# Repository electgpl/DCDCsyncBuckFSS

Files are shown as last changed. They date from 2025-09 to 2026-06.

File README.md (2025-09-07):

# High-Performance Synchronous Buck Converter Module (AP64501)

This project is the design of a **DC-DC buck regulator module** based on the **AP64501**.  
It is mechanically and electrically compatible with the popular **LM2596-based low-cost Chinese modules**, using the same form factor, size, and pinout.  
However, this design provides **significant improvements** in terms of efficiency, thermal performance, EMI, and reliability.

---
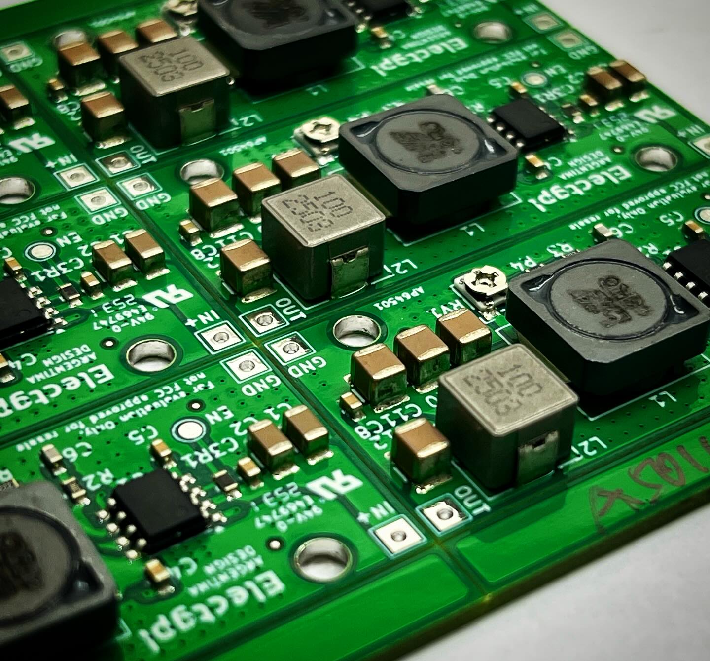
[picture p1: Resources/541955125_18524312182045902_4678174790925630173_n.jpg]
Module Preview

---

## 🔑 Key Features

- **Synchronous buck regulator (AP64501)**
  - Higher efficiency compared to asynchronous regulators.
  - Reduced heat generation under load.
- **Fixed Spread Spectrum (FSS)**
  - Lower EMI and more predictable spectral content.
- **Soft-Start (SS)**
  - Controlled inrush current during power-up.
- **Protections included**
  - Overcurrent protection (OCP).
  - Overvoltage protection (OVP).
  - Thermal shutdown (TSD).
- **Output filtering**
  - Additional **LC filter stage** for significantly reduced ripple.
- **PCB design**
  - **4-layer PCB** for improved heat spreading and ground integrity.
  - Optimized layout for EMI and thermal performance.
- **Thermal analysis**
  - Finite Element Analysis (FEA) performed.
  - Effective thermal resistance: **55 °C/W** (with 1 oz copper).

---

## 📐 Form Factor

- Pinout, size, and footprint are **drop-in compatible** with standard LM2596-based modules.  
- This allows easy replacement in existing designs, providing an **immediate upgrade** without redesigning the host PCB.

---

## 📊 Performance Advantages over LM2596 Modules

- ✅ Higher efficiency → less power loss.  
- ✅ Lower EMI thanks to fixed-frequency operation and optimized layout.  
- ✅ Lower output ripple due to additional LC stage.  
- ✅ Improved thermal performance with 4-layer PCB and synchronous design.  
- ✅ Built-in protections increase reliability and robustness.

---

## 🛠 Applications

- Embedded systems.  
- IoT devices.  
- RF front-ends (low-ripple supply requirement).  
- General-purpose regulated DC power supply.  
- Replacement for LM2596 modules in existing projects.

---

## 📄 Documentation

- [AP64501 Datasheet (Diodes Incorporated)](https://www.diodes.com/assets/Datasheets/AP64501.pdf)  
- Thermal FEA analysis results included in `/docs`.  
- PCB design files in `/hardware`.

---

## 🚀 Status

- ✅ Schematic design complete.  
- ✅ PCB layout (4-layer) completed.  
- ✅ Thermal simulation results validated.  
- 🔜 Hardware prototyping and testing in progress.

---

## 📷 Preview

*(Add photos, renderings, or thermal plots here when available.)*

---

## 📜 License

This project is released under the **MIT License**.  
See the [LICENSE](LICENSE) file for details.

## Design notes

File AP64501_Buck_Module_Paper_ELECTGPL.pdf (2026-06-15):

# 5 A Spread-Spectrum Synchronous Buck Module with a Two-Stage Output Filter: Design and Experimental Characterization

Sebastián Caccavallo
Electgpl
Advanced Hardware Design | Aerospace - Military - Medical

Abstract—This paper presents the design and experimental characterization of a 5 A step-down (buck) power module intended as a higher-performance, pin- and form-compatible replacement for the ubiquitous LM2596 module. The converter is built around the Diodes AP64501 synchronous buck (3.8–40 V input, peak-current-mode control at 570 kHz, integrated 45 mΩ/20 mΩ power MOSFETs and ±6 % frequency spread spectrum) and is implemented on a four-layer printed circuit board with a continuous return-reference plane and a thermal via array beneath the exposed pad. A distinctive feature is a two-stage output filter in which the control-loop feedback is deliberately sampled before the second-stage LC network, preserving the manufacturer reference type-II compensation while relegating the post-filter to a passive role. The module was characterized at Vin≈12 V, Vout≈4.8 V, up to 1.155 A. Measured peak efficiency is 87.8 %, output ripple is 7.8 mV
pp

(≈0.16 % of Vout), the hotspot temperature is 34.8 °C (ΔT≈11 °C), and radiated emissions remain below the displayed CISPR 32 envelope with ≈3 dB worst-case margin near 200 MHz. The 2.23 % load regulation is shown—analytically and by inspection of the schematic—to originate almost entirely from the DC resistance of the out-of-loop second-stage inductor rather than from the regulation loop. Design trade-offs and recommended follow-up measurements are discussed.

Index Terms—Synchronous buck converter, AP64501, spread-spectrum modulation, electromagnetic interference (EMI), output-voltage ripple, two-stage LC filter, load regulation, output impedance, power-distribution network, CISPR 32, four-layer PCB.

Manuscript compiled June 14, 2026 (Rev. C). The author is with Electgpl, Buenos Aires, Argentina (https://github.com/electgpl). Design performed in KiCad 9.0.4; device under test based on the Diodes AP64501SP-13. Prototype labeled “For evaluation only — not FCC approved for resale.” Ambient temperature for the thermal measurement was not logged and is assumed ≈24 °C where noted.

I. Introduction

The LM2596-based step-down module is one of the most widely deployed power bricks in hobbyist and low-volume industrial designs, owing to its low cost and convenient form factor. Its limitations are equally well known: an asynchronous topology with a Schottky catch diode, a switching frequency near 150 kHz, modest light-load efficiency, comparatively high output ripple, and no provision for electromagnetic-interference (EMI) mitigation. This work targets a mechanically compatible replacement that retains the familiar IN+/GND/OUT/EN interface while substantially improving switching performance, output ripple, thermal behavior and radiated emissions.
The design is built around the Diodes AP64501, a 5 A synchronous buck converter with a 3.8–40 V input range, peak-current-mode control at a fixed 570 kHz internal clock, fully integrated 45 mΩ (high-side) and 20 mΩ (low-side) power MOSFETs, a proprietary gate-driver scheme that controls switch-node ringing, and frequency spread spectrum (FSS) with ±6 % jitter for EMI reduction [1]. The contribution of this paper is twofold: (i) a complete, reproducible design record (schematic, bill of materials and four-layer stack-up) of an EMI-aware module, and (ii) a full experimental characterization—efficiency, output ripple, thermal imaging and radiated emissions—together with an analysis of the two-stage output-filter trade-off that explains the measured efficiency and load-regulation figures.

Electgpl — Technical Report | AP64501 Buck Module · Design and Characterization

II. Power-Stage Architecture and Schematic

A. Integrated Converter
The AP64501 employs fixed-frequency peak-current-mode control with an internal 0.8 V ±1 % reference, programmable soft-start, cycle-by-cycle current limit with entry into hiccup mode after 512 consecutive limit events, output over-voltage protection, EN-programmable under-voltage lockout and thermal shutdown [1]. The device is supplied in an SO-8EP package whose exposed pad provides the primary thermal path.
B. Two-Stage Power Train and Capacitance Partition
The converter migrates the LM2596 interface from a 150 kHz asynchronous stage to a 570 kHz synchronous one and adds a second-stage output filter. It is essential to distinguish which output capacitance is inside and outside the control loop, since this governs both stability and load regulation. Table I summarizes the partition.

TABLE I
Output Capacitance Partition and Loop Relationship
Block | Components | Relationship to control loop
Input | C1, C2 = 2×10 µF + C3 100 nF | Input decoupling / input switching loop
First stage (buck) | L1 3.6 µH + C8 100 nF + C9/C10/C11 =
| 66 µF | Regulated node — feedback is sensed here

Second stage

(post-filter) | L2 10 µH + C12 22 µF | Outside the loop — passive ripple/EMI attenuation

The first-stage node presents 66 µF of ceramic capacitance—identical to the 3×22 µF Cout of the manufacturer reference design [1]—so the reference type-II compensation (R2 = 15.8 kΩ, C6 = 2.7 nF) remains valid. The post-filter (L2, C12) is added downstream of the feedback tap and therefore does not alter the loop, at the cost of the DC drop of L2 (Section V-C).

C. Feedback Sensed Before the Filter
A design note on the schematic states explicitly that the feedback sample is taken before the LC filter, so as not to alter the compensation phase of the converter nor add a new pole. This is a deliberate and well-founded choice: it keeps the loop identical to the reference (stable, with 66 µF and type-II compensation) and leaves the second stage as a purely passive filter. The output is made adjustable by the divider
Vout = Vref · ( 1 + Rtop / Rbot ) | (1)

with upper branch R4 (100 Ω) in series with trimmer RV1 (47 kΩ) taken from the regulated node, lower resistor R3 (2.2 kΩ) to ground, and a feed-forward capacitor C7 (10 nF) across the upper branch to introduce a phase-lead zero. With Vref=0.8 V and R3=2.2 kΩ, the measured 4.86 V set-point corresponds to Rtop≈11 kΩ (RV1 at roughly one quarter of travel); the theoretical adjustment range is ≈0.84 V to ≈18 V, bounded in practice by Vin headroom.

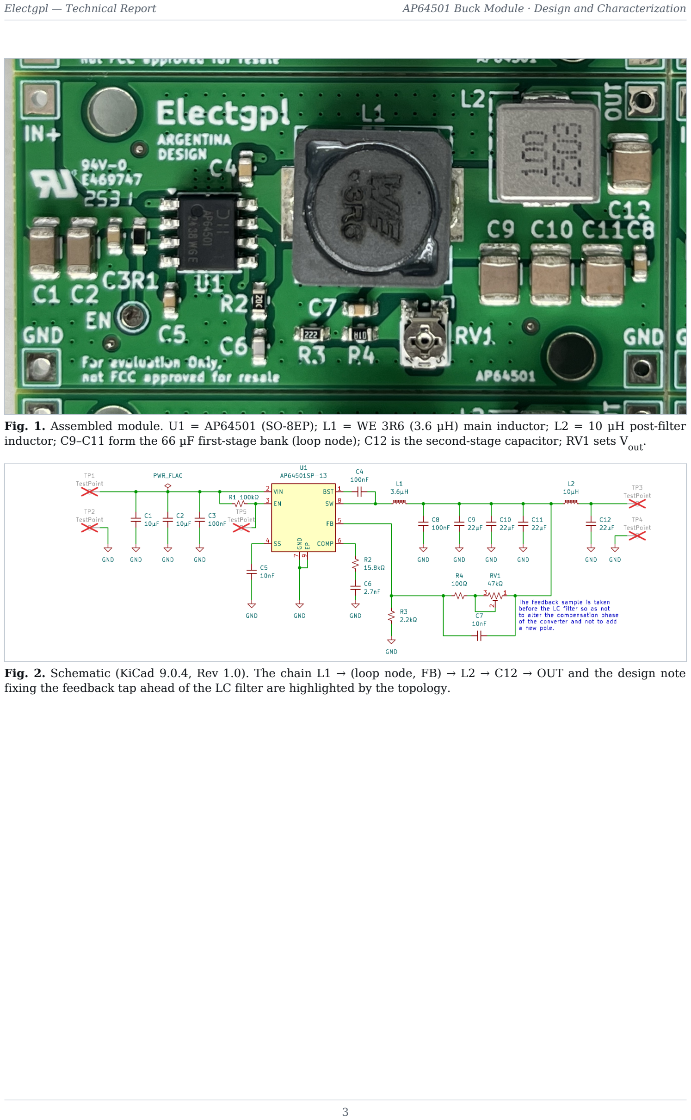
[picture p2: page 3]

Fig. 1. Assembled module. U1 = AP64501 (SO-8EP); L1 = WE 3R6 (3.6 µH) main inductor; L2 = 10 µH post-filter inductor; C9–C11 form the 66 µF first-stage bank (loop node); C12 is the second-stage capacitor; RV1 sets Vout.

Fig. 2. Schematic (KiCad 9.0.4, Rev 1.0). The chain L1 → (loop node, FB) → L2 → C12 → OUT and the design note fixing the feedback tap ahead of the LC filter are highlighted by the topology.

TABLE II
Bill of Materials
Ref. | Value | Function
U1 | AP64501SP-13 | 5 A synchronous buck (SO-8EP, EP to GND)
L1 | 3.6 µH (WE 3R6) | Main inductor — first stage
L2 | 10 µH | Post-filter inductor — second stage
C1, C2 | 10 µF each | Input capacitors (ceramic)
C3 | 100 nF | Input high-frequency decoupling
C4 | 100 nF | Bootstrap (BST–SW)
C5 | 10 nF | Soft-start (SS)
C6 | 2.7 nF | Type-II compensation (COMP)
C7 | 10 nF | Feedback feed-forward
C8 | 100 nF | First-stage output, high frequency
C9, C10, C11 | 22 µF each (66 µF) | First-stage bulk (loop node)
C12 | 22 µF | Second-stage output (post-filter, out of loop)
R1 | 100 kΩ | EN pull-up / UVLO setting
R2 | 15.8 kΩ | Type-II compensation (COMP)
R3 | 2.2 kΩ | Feedback divider (lower)
R4 | 100 Ω | Feedback divider (upper series)
RV1 | 47 kΩ (trimmer) | Output-voltage adjustment
TP1–TP5 | — | Test points (Vin, EN, Vout, nodes)
FID1–FID3 | — | Assembly fiducials

III. Printed-Circuit Implementation

The board is realized on four copper layers, a decision central to the measured power-integrity and EMI performance. Table III lists the function of each layer as inferred from the copper artwork (Fig. 3).

TABLE III
Function of Each Copper Layer
Layer | Design observation | Implication
TOP | Components and power copper: Vin input, a compact
SW node, the first-stage (loop) node and OUT.

Input switching loop and SW node of minimal area → reduced di/dt radiating area.

INNER1 Continuous reference (GND) plane directly beneath TOP.

Low-inductance image-current return for every power trace → key to the clean CISPR scan.

INNER2 | Additional plane (GND/power) with stitching-via field. | Reinforces the PDN and inter-layer
shielding; low plane impedance.

BOTTOM Sensitive signal routing (feedback) plus GND fill.

Feedback routed away from SW, referenced to an inner plane → low noise on the regulated node.

Two cross-cutting features stand out: a dense GND stitching-via field that ties the planes together across all layers, providing return continuity and shielding; and a thermal via array beneath the exposed pad of U1 (white outline in Fig. 3), which channels heat from the EP into the inner and bottom copper—consistent with the ≈12 °C/W effective thermal resistance estimated in Section V-E. The continuous return plane on INNER1 under the TOP power copper, the compact SW node and the device FSS jointly account for the low radiated-emission levels

(Section V-F).

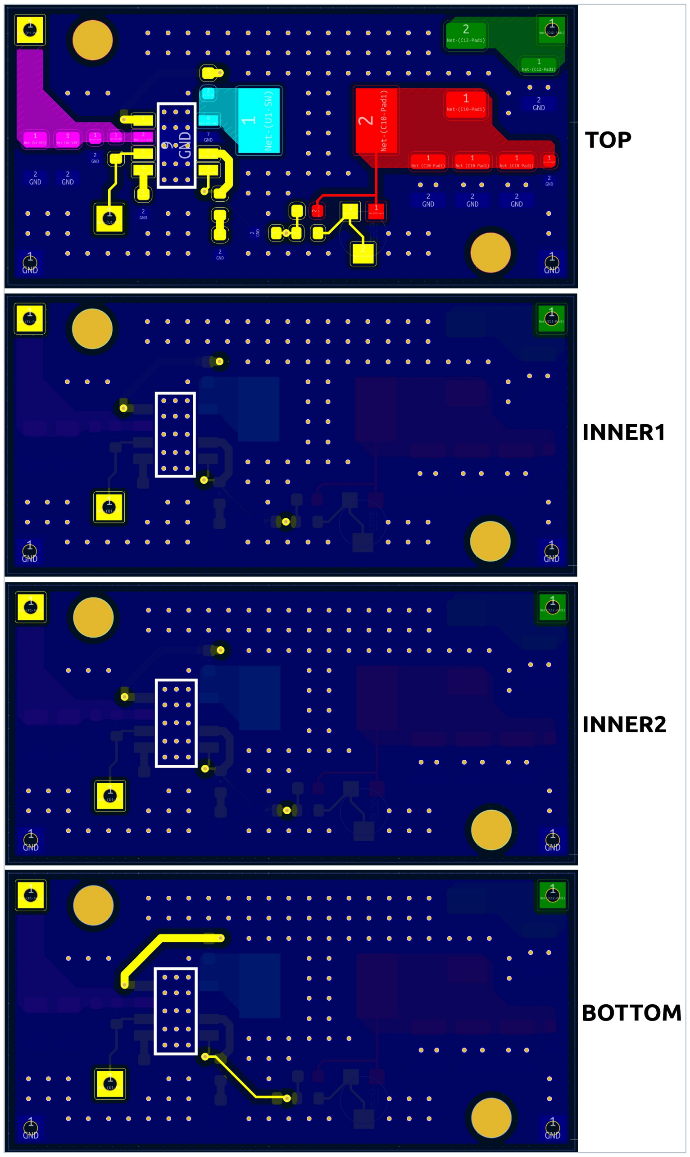
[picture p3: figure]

Fig. 3. Four-layer artwork (TOP / INNER1 / INNER2 / BOTTOM). White outline: thermal/GND via array beneath the U1 exposed pad. Yellow dots: the GND stitching-via field.

IV. Experimental Method

The module was supplied from a bench source at Vin≈12 V (logged average 11.879 V) with the output trimmed to ≈4.8 V. An electronic load swept the output current from 0 to 1.155 A in 30 steps, averaging 16 readings per point with a 0.25 s settling interval. Table IV lists the instrumentation and conditions.

TABLE IV
Test Conditions and Instrumentation
Quantity / instrument | Configuration
Input voltage | Vin≈12 V (measured 11.879 V), bench supply
Output voltage | ≈4.8–4.86 V, set by RV1
Load sweep | Electronic load, 30 steps, 0→1.155 A, 0.25 s settle, 16-sample average
Bench power budget | Pbudget=15 W (caps the swept Iout)
Ripple | Rigol oscilloscope, CH1 5 mV/div, statistical Ripple function (1000 counts),
| 20 MHz bandwidth limit
Thermal | IR camera (iron palette), board in still air, no heatsink or forced flow
EMC | Radiated emissions 30 MHz–1 GHz against a CISPR 32 envelope
| (40/47 dBµV/m)

The sweep terminated at 1.155 A because of the 15 W bench budget, not a device limitation: the automated report records “3 %/5 %/10 % drop: not reached” and “no cutoff,” meaning the output never sagged enough to trigger the drop thresholds and the AP64501 current limit was not reached. The present campaign therefore covers operation up to ≈1.16 A; determining the true maximum output current (toward the 5 A device rating) requires a higher-power bench and is left as future work (Section VI).

V. Results and Discussion

Table V collects the headline measured figures; the subsections that follow analyze each result.

| TABLE V
Summary of Measured Performance
Parameter | Result | Condition / note
Vout, no load | 4.861 V | I out=0 (trimmed by RV1)
Vout, full load | 4.752 V | I out=1.155 A
Load regulation | 2.23 % (Rout,eq≈94 mΩ) | 0→1.155 A; root cause in V-C
Max. swept Iout | 1.155 A | bench-limited; Ilim not reached
Peak / full-load efficiency | 87.8 % @0.84 A / 87.0 % @1.16 A | max. loss 0.90 W

Output ripple (pp, BW
20 MHz) | 7.76 mV typ. / 11.84 mV max | ≈0.16 % of Vout
Thermal hotspot | 34.8 °C | ΔT≈11 °C over assumed ~24 °C ambient
Radiated emissions | Below 40/47 dBµV/m envelope | ≈3 dB worst-case margin (~200 MHz)
A. Efficiency and Power Balance

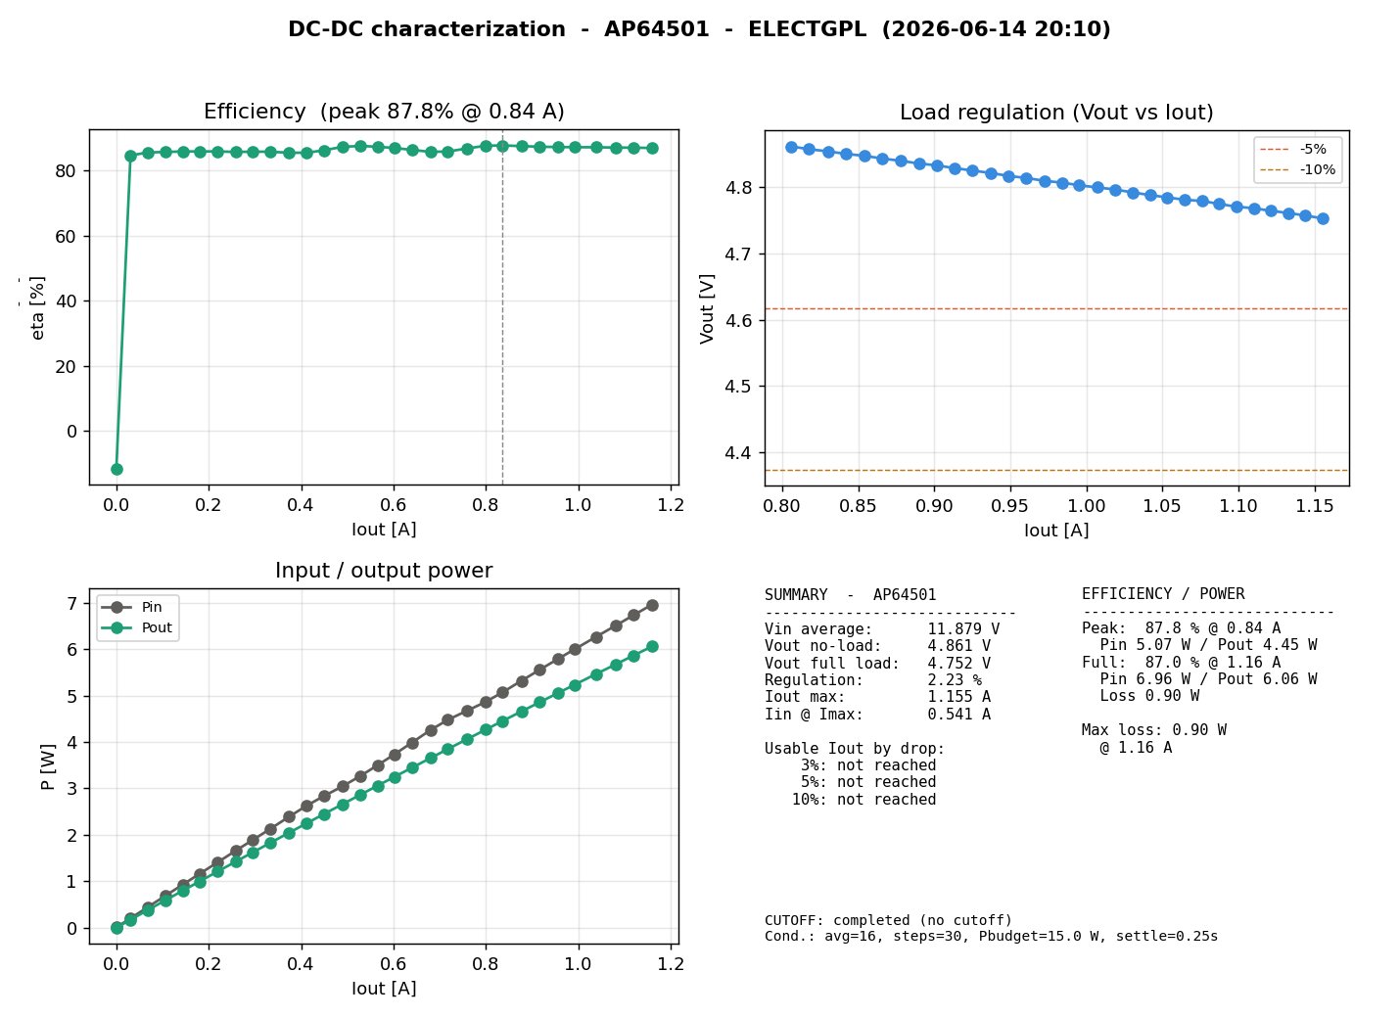
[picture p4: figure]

Fig. 4. Automated DC-DC characterization: efficiency η(Iout), load regulation Vout(Iout) and input/output power, with the bench numeric summary at right.

Efficiency is flat at 86–88 % across the continuous-conduction region, peaking at 87.8 % at 0.84 A and reaching 87.0 % at full load (1.16 A), where the total loss is 0.90 W. The first sweep point (Iout→0) falls below zero by definition of η=Pout/Pin at no load (Pout=0 while the device still draws switching and quiescent current); it is an artifact, not a physical efficiency.
For the 12 V→4.8 V operating point the bare-IC reference design exceeds 90 % [1],[2]; the module delivers ≈87–88 %, a 3–6-point module-level deficit. With the bill of materials now confirmed, the dominant contributors are, in order: (i) the DC resistance of the out-of-loop second-stage inductor L2 (10 µH), which carries the full DC output current—at DCR≈80 mΩ this is I²·DCR≈0.11 W at 1.16 A, about 12 % of the measured loss; (ii) the DCR of L1 and interconnect; and (iii) the operating point, since 1.16 A is well below the peak-efficiency load of a 5 A converter, so fixed losses weigh proportionally more. Conduction losses in the integrated
MOSFETs | are | bounded: | high-side | ≈D·I²·RHS=0.40·1.16²·0.045≈24 | mW | and | low-side
≈0.60·1.16²·0.020≈16 mW. The trade-off is consistent with the design intent: the post-filter trades a few points of efficiency for ripple and EMI.
B. Inductor Ripple, CCM and Filter Corners
The peak-to-peak ripple current of the main inductor in steady state is
| | ΔIL

= Vout(Vin − Vout) / (Vin L1

| | | | f sw
| | | | ) | | | (2)

which evaluates to ΔIL
≈1.40 A
| | | pp

(≈28 % of the 5 A rating; the usual 20–40 % guideline). The inductor-current valley at 1.16 A is 1.16−0.70=0.46 A>0, so the converter operates in continuous conduction (CCM); the CCM/PFM boundary lies at ≈0.70 A. Each LC corner follows from

| | | f c
= 1 / ( 2π √(L C) ) | (3)

yielding the values in Table VI.

TABLE VI
Distributed-Element and Filter Parameters
Stage / quantity | Expression | Value
First-stage LC (in loop) | f
| c1=1/(2π√(L1·66 µF)), L1=3.6 µH | ≈10.3 kHz
Second-stage LC (post-filter) | f
| c2=1/(2π√(L2·C12)), L2=10 µH, C12=22 µF | ≈10.7 kHz

Second-stage attenuation
@570 kHz | (f
| sw
| /fc2)² (ideal, before C12 ESR zero) | ≈69 dB

Second-stage characteristic
impedance | Z0
| =√(L2/C12) | ≈0.67 Ω

The ≈60–70 dB of passive attenuation provided by the second stage at the switching frequency is the quantitative explanation for the very low measured ripple (Section V-D). A damping caveat applies: with Z0

≈0.67 Ω and only the L2 DCR (~80 mΩ) as damping, the second-stage quality factor is high (≈8) and, being outside the loop, may appear as ringing near 10.7 kHz at the OUT terminal under load steps. This should be verified with a load-transient test (Section VI); if present, an RC snubber across C12 damps it without touching the loop.

C. Load Regulation and Output Impedance
The measured load regulation is 2.23 % (4.861→4.752 V from no load to 1.155 A): a 109 mV drop over 1.155 A, equivalent to a static output resistance
Rout,eq = ΔVout / ΔIout ≈ DCRL2 + Rint ≈ 94 mΩ | (4)

The schematic confirms the root cause: feedback is sensed at the first-stage node, by explicit design choice, so the loop regulates that node accurately while the DC resistance of L2 (10 µH) lies outside the loop and appears in full as load droop at OUT. The 94 mΩ figure is fully compatible with the DCR of a compact 10 µH molded inductor (≈60–90 mΩ) plus trace and connector resistance—not with a loop deficiency, whose intrinsic DC regulation is <0.5 %.
The decision is technically sound: sensing after L2 would bring the second stage inside the loop, adding an LC pole that erodes phase margin—precisely what the design avoids. Three options exist, in increasing order of intervention: (a) accept and specify the 94 mΩ as the module output impedance (simplest and most honest for a datasheet); (b) reduce the L2 DCR (a larger-section, lower-DCR inductor) to lower the droop without touching the loop; and (c), only if the application demands tight regulation at OUT, sense in Kelvin after L2 with a feed-forward/phase-lead network that restores the high-frequency information of the pre-L2 node and preserves margin, at the cost of added compensation complexity. A four-wire measurement of the L2 DCR is recommended first, to confirm it dominates the 94 mΩ.
D. Output Ripple and Noise

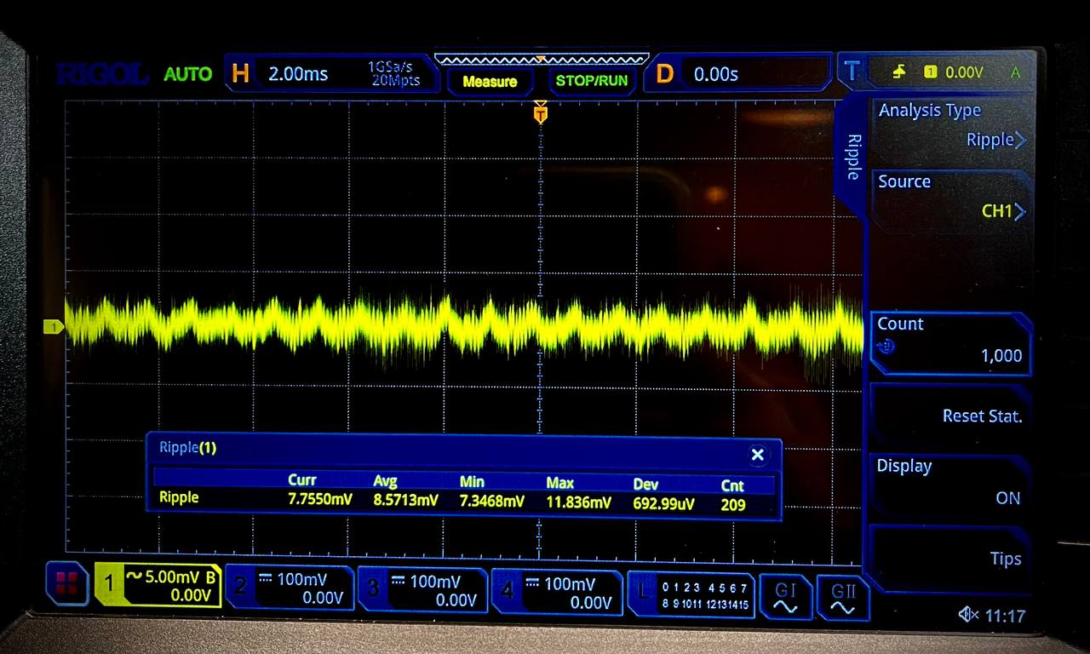
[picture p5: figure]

Fig. 5. Output ripple (Rigol, 5 mV/div, 20 MHz bandwidth limit, 1000 counts): Vpp

7.755 mV (mean
8.571, max 11.836, σ 0.69 mV).

Output ripple-plus-noise is 7.76 mV
pp

(mean 8.57, max 11.84), i.e. ≈0.16 % of Vout—a strong result and the direct benefit of the second-stage post-filter (Section V-B: ≈69 dB attenuation at f
sw

). The 20 MHz bandwidth limit (indicator “B”) was engaged, standard practice to bound RF pickup.
Two measurement caveats keep the figure defensible. First, the 2 ms/div timebase does not resolve the 570 kHz fundamental (1.75 µs period); the instrument’s Ripple function computes V
pp

statistically over the whole record (≈20 ms), so the value is valid as peak-to-peak ripple-plus-noise but mixes switching ripple with low-frequency wander and any pickup. Second, a zoomed capture (~500 ns/div) with a tip-and-barrel probe across C12—eliminating the alligator ground loop—should confirm the switching-ripple waveform; the ≈8 mV
pp

figure is expected to
hold or improve.
E. Thermal Performance

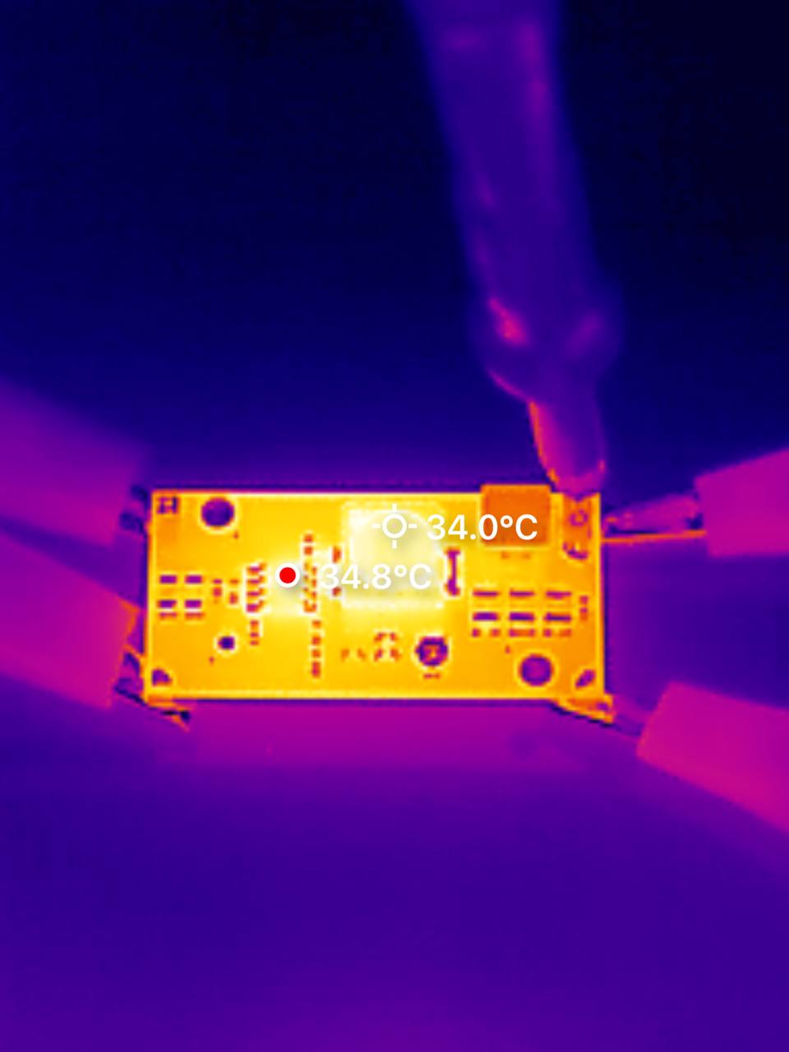
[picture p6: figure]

Fig. 6. Thermography. Crosshair 34.0 °C; spot 34.8 °C. Board in still air, no heatsink.

Operating in still air without heatsink or forced ventilation, the hotspot reads 34.8 °C and the board averages ≈34.0 °C. Assuming an ambient of ≈24 °C (not logged), the rise is ΔT≈11 °C for ≈0.9 W of loss, giving an effective hotspot-to-ambient thermal resistance of ≈12 °C/W—excellent for an SO-8EP with exposed pad on four layers with a thermal via array (Section III). An emissivity caveat applies: IR cameras under-read shiny metal surfaces (inductor can, IC body) owing to low emissivity, whereas readings on the PCB solder mask (ε≈0.9) are reliable; metallic parts may therefore be somewhat hotter than displayed. Even so, the margin is wide: the temperature confirms ample headroom to operate well above 1.16 A before any thermal limit.

F. Radiated Emissions (CISPR 32)

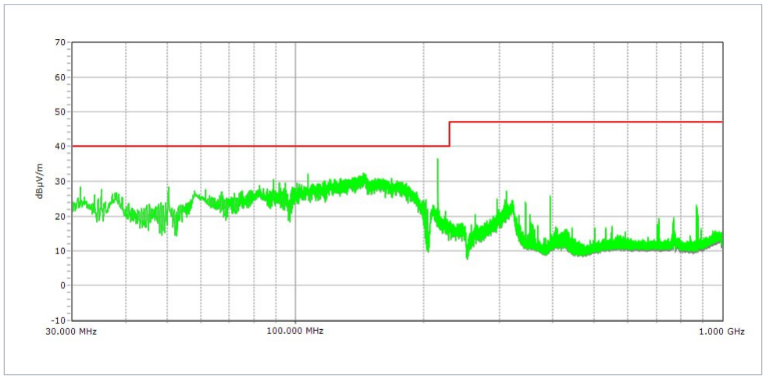
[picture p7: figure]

Fig. 7. Radiated emissions 30 MHz–1 GHz (green) against the limit envelope (red): 40 dBµV/m (30–230 MHz) and 47 dBµV/m (230 MHz–1 GHz).

The trace remains below the envelope across the band. The displayed limits (40/47 dBµV/m) correspond to CISPR 32 Class B at 3 m (equivalently Class A at 10 m) [4]. The measured level mostly lies between 20 and 35 dBµV/m, with a broadband hump between ≈100 and ≈200 MHz reaching ≈37 dBµV/m—the worst case, at ≈3 dB margin; above 230 MHz the margin exceeds 10 dB.
This is consistent with the design: the AP64501 FSS (±6 %) spreads each switching harmonic and lowers peak-detector levels [1]; the continuous return plane on INNER1 under the TOP power copper minimizes di/dt loop area; and the second-stage post-filter attenuates common-mode current toward the output cabling—the principal radiation mechanism in modules of this type. The 100–200 MHz hump has the signature of common-mode current on the I/O cables rather than a direct switching harmonic, and is the feature to watch for additional margin (an input/output ferrite bead or reinforced common-mode filtering). The scan is a pre-compliance peak-detector measurement; the distance, antenna and chamber are not recorded, and quasi-peak/average detectors are not shown. It is adequate to validate the design and estimate margin, but formal conformance requires an accredited measurement.

VI. Conclusion and Recommended Work

A four-layer, EMI-aware 5 A synchronous buck module was designed and characterized as a higher-performance, form-compatible alternative to the LM2596 module. At 12 V→4.8 V it achieves 570 kHz synchronous switching, ≈8 mV
pp

output ripple, a wide thermal margin (ΔT≈11 °C for ≈0.9 W), and radiated emissions below the displayed CISPR 32 envelope, with no protection event over the swept range. The two seemingly weak figures—≈87 % efficiency and 2.23 % load regulation—are shown to be the quantified, deliberate consequence of a two-stage output filter with pre-filter feedback, not a defect: the load droop is dominated by the out-of-loop L2 DC resistance, and the efficiency deficit is largely the same series resistance plus a light operating point for a 5 A device. Table VII lists the recommended follow-up measurements that would close the remaining open items.

TABLE VII
Recommended Follow-up Measurements
# | Action | Objective

1 | Four-wire DCR of L1 and L2; re-test toward Ilim/thermal rollback (3–5 A) on a higher-power bench. | Quantify the efficiency/regulation split; establish true maximum current (now bench-limited to 1.16 A).
2 | Load-transient (step) test observing OUT and the loop node. | Check for the ≈10.7 kHz second-stage ringing (Q≈8) outside the loop; decide on an RC snubber across C12.
3 | Zoomed ripple capture (~500 ns/div) with a tip-and-barrel probe across C12. | Quantify true switching ripple, separated from low-frequency content and pickup.
4 | If tight regulation is required: lower-DCR L2, or Kelvin sensing after L2 with feed-forward. | Reduce the 94 mΩ output impedance while preserving phase margin.
5 | Quasi-peak pre-compliance; mitigate common mode on I/O cabling (ferrite bead) over the 100–200 MHz hump. | Secure margin before an accredited measurement.
6 | Thermal sweep vs. load with logged ambient and, where applicable, at Vin=40 V. | Map Rθ/derating (a buck’s thermal worst case is usually at high Vin).

References

[1] Diodes Incorporated, “AP64501 — 3.8 V to 40 V Input, 5 A Low IQ
| | Synchronous Buck with Programmable
Soft-Start Time,” Datasheet DS41980, Rev. 5. Key parameters: 5 A, peak-current-mode, f
sw

=570 kHz, Rds(on)
45/20 mΩ, FSS ±6 %, Vref=0.8 V, reference Cout=3×22 µF, L=3.6 µH (5 V), SO-8EP.
[2] Diodes Incorporated, “AP64501SP-EVM — 40 V, 5 A, Low IQ
| | Synchronous DC-DC Buck Converter Evaluation
| Board User Guide.”
[3] Würth Elektronik, AP64501 reference-design data (3.6 µH “3R6” inductor), we-online.com, ICref / Diodes
| Incorporated section.

[4] CISPR 32:2015 / EN 55032, “Electromagnetic Compatibility of Multimedia Equipment — Emission Requirements,” radiated-emission Class A/B limits (40/47 dBµV/m, class- and distance-dependent).
[5] Good practice for switching-converter ripple measurement: tip-and-barrel / coaxial probing at the output capacitor with a 20 MHz bandwidth limit to bound RF pickup.

This document was compiled from the KiCad project (schematic Rev 1.0, four-layer artwork) and the bench reports of the device under test (automated DC-DC characterization, thermography, ripple and radiated emissions) dated 2026-06-14. Derived quantities (Rout,eq, ΔIL

, LC corners, attenuation, loss balance, effective Rθ) were computed from those data under the assumptions stated in each section. The DCR of L1/L2 and the true maximum output current remain to be measured directly.

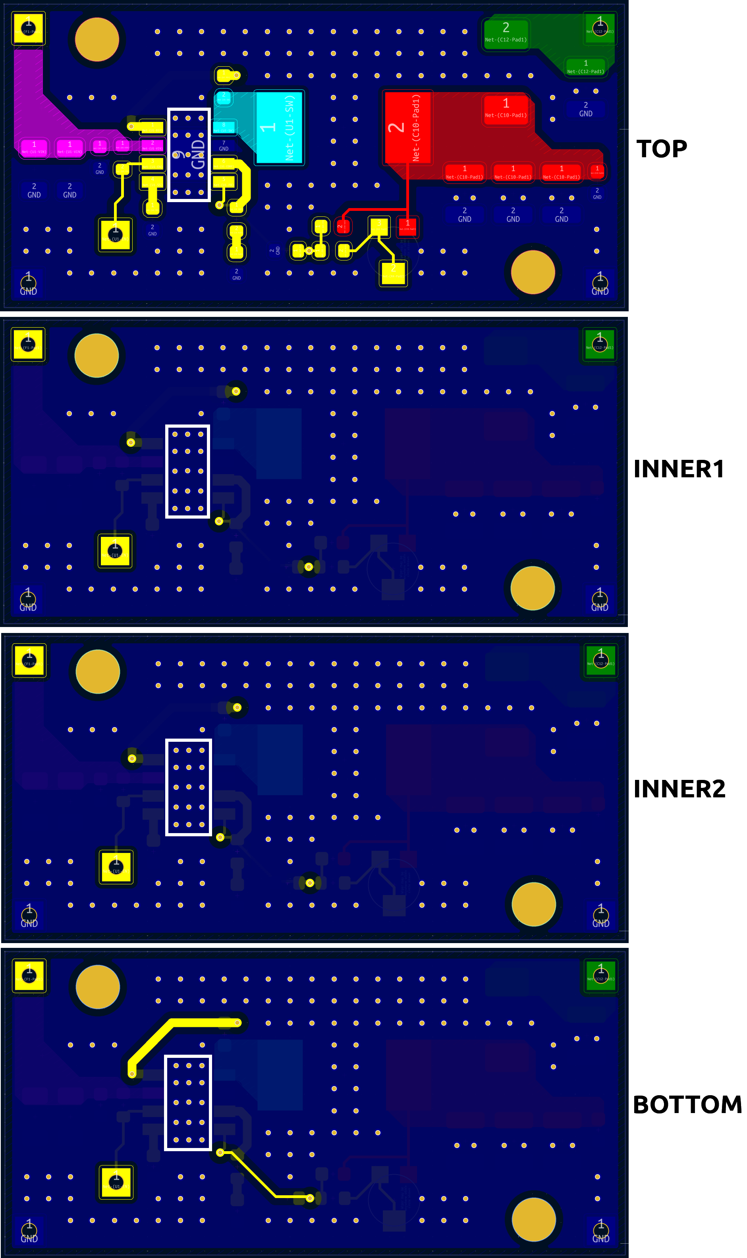
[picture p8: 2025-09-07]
PCB/EMI_SS_Supply_Electgpl/Multilayer.png

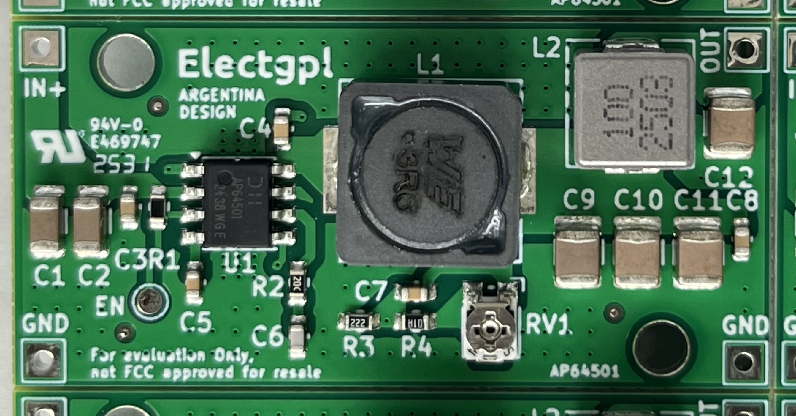
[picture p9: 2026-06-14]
Resources/Foto_PCBA.jpg

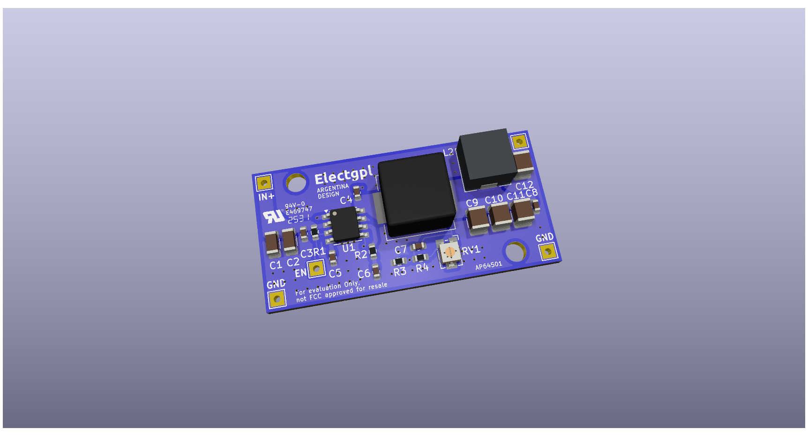
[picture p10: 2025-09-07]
PCB/EMI_SS_Supply_Electgpl/EMI_SS_Supply_Electgpl.png

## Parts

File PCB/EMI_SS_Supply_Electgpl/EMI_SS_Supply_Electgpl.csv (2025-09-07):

Reference | Qty | Value | MPN# | DNP | Footprint
C1,C2 | 2 | 10µF | CL31B106KBHNNNE |  | Capacitor_SMD:C_1206_3216Metric
C3,C4,C8 | 3 | 100nF | 885012206095 |  | Capacitor_SMD:C_0603_1608Metric
C5,C7 | 2 | 10nF | 885012206065 |  | Capacitor_SMD:C_0603_1608Metric
C6 | 1 | 2.7nF | GRM1885C1H272JA01D |  | Capacitor_SMD:C_0603_1608Metric
C9,C10,C11,C12 | 4 | 22µF | CL32B226KOJNNNE |  | Capacitor_SMD:C_1210_3225Metric
L1 | 1 | 3.6µH | 7447797360 |  | Inductor_SMD:L_Vishay_IHLP-4040
L2 | 1 | 10µH | SRP7050AA-100M |  | Inductor_SMD:L_Wuerth_HCM-7050
R1 | 1 | 100kΩ | CRCW0603100KFKEA |  | Resistor_SMD:R_0603_1608Metric
R2 | 1 | 15.8kΩ | CR0603-FX-1582ELF |  | Resistor_SMD:R_0603_1608Metric
R3 | 1 | 2.2kΩ | ERA-3AEB222V |  | Resistor_SMD:R_0603_1608Metric
R4 | 1 | 100Ω | AT0603DRD07100RL |  | Resistor_SMD:R_0603_1608Metric
RV1 | 1 | 47kΩ | TC33X-1-473E |  | Potentiometer_SMD:Potentiometer_Bourns_TC33X_Vertical
TP1,TP2,TP3,TP4,TP5 | 5 | TestPoint |  | DNP | TestPoint:TestPoint_THTPad_2.0x2.0mm_Drill1.0mm
U1 | 1 | AP64501SP-13 | AP64501SP-13 |  | Package_SO:Diodes_SO-8EP

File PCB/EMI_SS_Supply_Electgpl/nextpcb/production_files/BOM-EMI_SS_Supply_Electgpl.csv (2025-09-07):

MPN | Qty | Designator | value | manufacturer | Category | SKU | Customer Supply | Customer Remark
 | 2 | C1,C2 | 10µF
 | 6 | C5,C7,C6,C4,C8,C3 | 10nF
 | 4 | C12,C11,C10,C9 | 22µF
 | 1 | L1 | 3.6µH
 | 1 | L2 | 10µH
 | 4 | R4,R3,R1,R2 | 100Ω
 | 1 | RV1 | 47kΩ
 | 5 | TP5,TP4,TP3,TP1,TP2 | TestPoint
 | 1 | U1 | AP64501

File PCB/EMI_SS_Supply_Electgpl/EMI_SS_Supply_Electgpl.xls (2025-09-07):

Designator* | Quantity* | Manufacturer Part Number* | Manufacturer | Package/Footprint | Description | Procurement Type | Customer Note
Required | Required | Required |  |  |  | Optional 1）Do not populate/install: DNP 2）Customer supplied part: C Learn more >
C1,C2 | 2 | CL31B106KBHNNNE
C3,C4,C8 | 3 | 885012206095
C5,C7 | 2 | 885012206065
C6 | 1 | GRM1885C1H272JA01D
C9,C10,C11,C12 | 4 | CL32B226KOJNNNE
L1 | 1 | 7447797360
L2 | 1 | SRP7050AA-100M
R1 | 1 | CRCW0603100KFKEA
R2 | 1 | CR0603-FX-1582ELF
R3 | 1 | ERA-3AEB222V
R4 | 1 | AT0603DRD07100RL
RV1 | 1 | TC33X-1-473E
TP1,TP2,TP3,TP4,TP5 | 5 |  |  |  |  | DNP
U1 | 1 | AP64501SP-13

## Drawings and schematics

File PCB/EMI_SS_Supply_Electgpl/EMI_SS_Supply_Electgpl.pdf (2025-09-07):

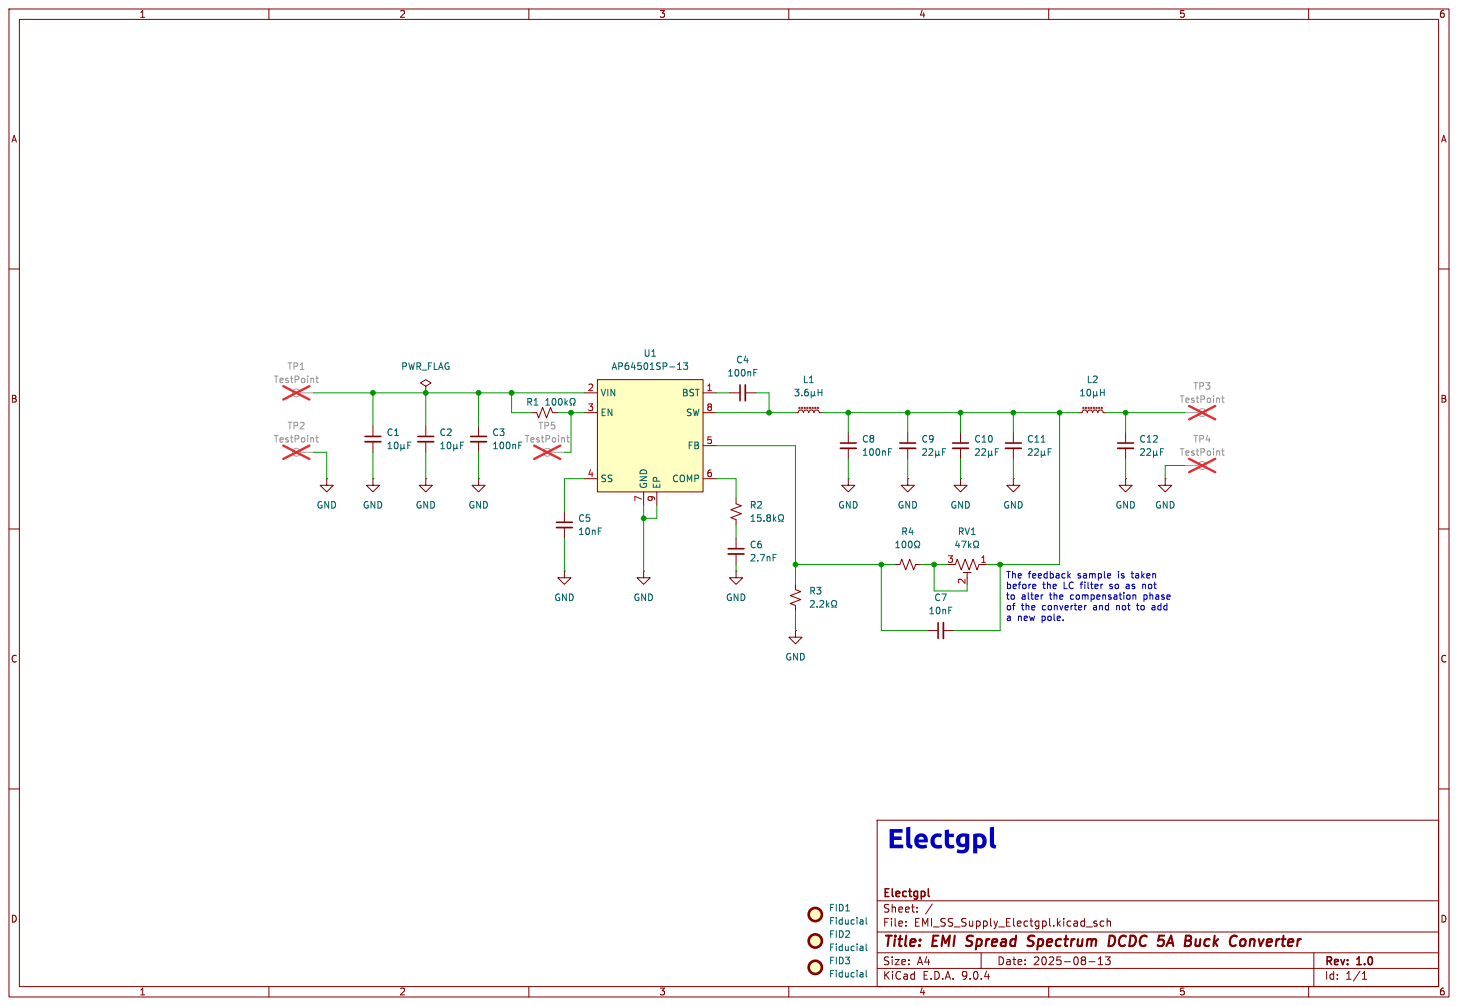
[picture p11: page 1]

9 BST 1 SW 8 FB 5 COMP 6 U1 AP64501SP-13 GND GND

Id: 1/1 Title: EMI Spread Spectrum DCDC 5A Buck Converter File: EMI_SS_Supply_Electgpl.kicad_sch Sheet: / Electgpl C6

The feedback sample is taken
before the LC filter so as not
a new pole.

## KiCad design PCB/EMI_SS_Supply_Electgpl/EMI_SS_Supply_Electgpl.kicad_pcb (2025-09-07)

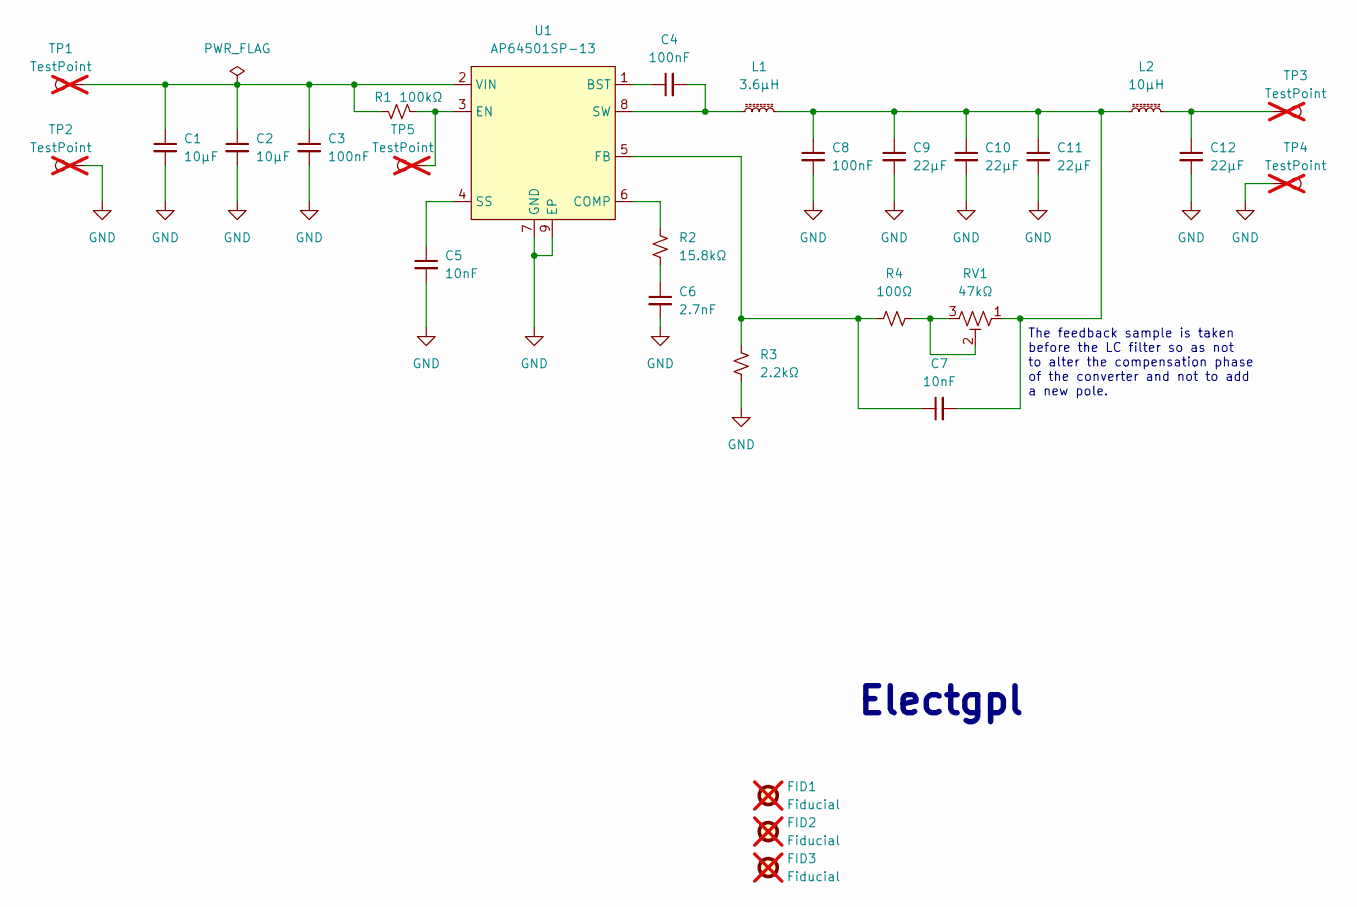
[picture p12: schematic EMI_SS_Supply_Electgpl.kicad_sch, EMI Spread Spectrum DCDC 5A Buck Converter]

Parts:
C1, C2: 10µF; C_1206_3216Metric; MPN# CL31B106KBHNNNE
C3, C4, C8: 100nF; C_0603_1608Metric; MPN# 885012206095
C5, C7: 10nF; C_0603_1608Metric; MPN# 885012206065
C6: 2.7nF; C_0603_1608Metric; MPN# GRM1885C1H272JA01D
C9, C10, C11, C12: 22µF; C_1210_3225Metric; MPN# CL32B226KOJNNNE
FID1, FID2, FID3: Fiducial; Fiducial_0.5mm_Mask1mm; not fitted
L1: 3.6µH; L_Vishay_IHLP-4040; MPN# 7447797360
L2: 10µH; L_Wuerth_HCM-7050; MPN# SRP7050AA-100M
R1: 100kΩ; R_0603_1608Metric; MPN# CRCW0603100KFKEA
R2: 15.8kΩ; R_0603_1608Metric; MPN# CR0603-FX-1582ELF
R3: 2.2kΩ; R_0603_1608Metric; MPN# ERA-3AEB222V
R4: 100Ω; R_0603_1608Metric; MPN# AT0603DRD07100RL
RV1: 47kΩ; Potentiometer_Bourns_TC33X_Vertical; MPN# TC33X-1-473E
TP1, TP2, TP3, TP4: TestPoint; TestPoint_THTPad_2.0x2.0mm_Drill1.0mm; not fitted
TP5: TestPoint; TestPoint_Pad_D1.5mm; not fitted
U1: AP64501SP-13; Diodes_SO-8EP; MPN# AP64501SP-13

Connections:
GND: C1.2, C2.2, C3.2, C5.2, C6.2, C8.2, C9.2, C10.2, C11.2, C12.2, R3.2, TP2.1, TP4.1, U1.7 (GND), U1.9 (EP)
unnamed: C6.1, R2.2
unnamed: C7.2, C8.1, C9.1, C10.1, C11.1, L1.2, L2.1, RV1.1
unnamed: C12.1, L2.2, TP3.1
unnamed: R4.2, RV1.2, RV1.3
unnamed: C4.1, U1.1 (BST)
unnamed: R2.1, U1.6 (COMP)
unnamed: R1.2, TP5.1, U1.3 (EN)
unnamed: C7.1, R3.1, R4.1, U1.5 (FB)
unnamed: C5.1, U1.4 (SS)
unnamed: C4.2, L1.1, U1.8 (SW)
unnamed: C1.1, C2.1, C3.1, R1.1, TP1.1, U1.2 (VIN)

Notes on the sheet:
Electgpl
The feedback sample is taken before the LC filter so as not to alter the compensation phase of the converter and not to add a new pole.

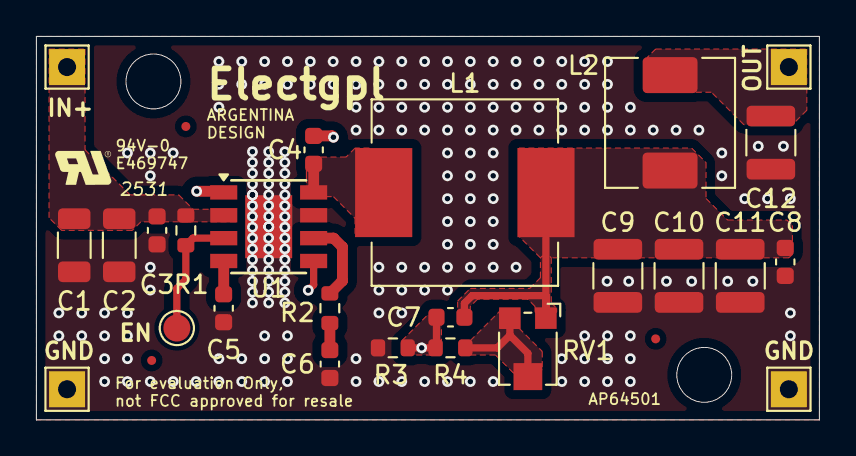
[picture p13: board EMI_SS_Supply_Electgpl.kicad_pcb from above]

Board: 4 copper layers, 43.5 x 21.3 mm, 28 parts (0 on the bottom side), 12 nets.
